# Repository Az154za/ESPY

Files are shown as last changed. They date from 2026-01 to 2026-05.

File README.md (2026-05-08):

# ESPY:
The main mcu is the esp32-P4 that allows fast lane data transmission allowing the camera and display option .
This project contains 4 layers 2 for signals 1 for 3V3 and one for Ground .  

The reason I chose the p4 is because it's very good for cameras .

-- feel free to grab gerber file and to print them yourself --
# Schematic :



# Routing :



# 3D overview : 


# BOM ( visual ) 

Total:192$

I hope you like this project

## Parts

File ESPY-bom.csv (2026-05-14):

Name | Purpose | Quantity | Total Cost (USD) | Link | Distributor
JLCPCB fees | Production fees | 1 | 96.00 |  | JLCPCB
JLCPCB fees | Price tolerance inflation | 1 | 5.00 |  | JLCPCB
Camera | Testing | 1 | 10.44 | https://fr.aliexpress.com/item/1005003386791483.html?pdp_ext_f=%7B"order"%3A"2144"%2C"spu_best_type"%3A"price"%2C"eval"%3A"1"%2C"fromPage"%3A"search"%7D&pdp_npi=6%40dis%21EUR%213.62%210.99%21%21%214.15%211.13%21%40211b813b17782729390364065e89b5%2112000034511448969%21sea%21FR%210%21ABX%211%210%21n_tag%3A-29910%3Bd%3A3d505027%3Bm03_new_user%3A-29895%3BpisId%3A5000000203225082&curPageLogUid=UVp1q8ZxinQD&utparam-url=scene%3Asearch%7Cquery_from%3A%7Cx_object_id%3A1005003386791483%7C_p_origin_prod%3A | ALIEXPRESS
C481407 | Crystal | 5 | 1.25 | https://jlcpcb.com/partdetail/NDK-NX3225GA_12MHZ_STD_CRG2/C481407 | JLCPCB
C5380316 | Crystal | 6 | 0.42 | https://jlcpcb.com/partdetail/SST-3225_40M_12PF10PPM/C5380316 | JLCPCB
C2962011 | FLASH SHIP ( 512 Mbits ) | 2 | 16.15 | https://jlcpcb.com/partdetail/WinbondElec-W25Q512JVFIQ/C2962011 | JLCPCB
C6798314 | USB_HUB ( SL2.1A ) | 2 | 0.53 | https://jlcpcb.com/partdetail/CoreChips-SL21A/C6798314 | JLCPCB
C398367 | Buck converters | 6 | 0.88 | https://jlcpcb.com/partdetail/TexasInstruments-TLV62569ADRLR/C398367 | JLCPCB
C22387510 | ESP-P4 | 2 | 11.58 | https://jlcpcb.com/partdetail/EspressifSystems-ESP32P4NRW32/C22387510 | JLCPCB
C115357 | switch | 5 | 0.66 | https://jlcpcb.com/partdetail/ALPSALPINE-SKRKAEE020/C115357 | JLCPCB
C137946 | resistor | 20 | 0.02 | https://jlcpcb.com/partdetail/YAGEO-RC0402FR076K2L/C137946 | JLCPCB
C25905 | resistor | 20 | 0.02 | https://jlcpcb.com/partdetail/26648-0402WGF5101TCE/C25905 | JLCPCB
C43251 | resistor | 20 | 0.02 | https://jlcpcb.com/partdetail/44242-0402WGF4021TCE/C43251 | JLCPCB
C25744 | resistor | 20 | 0.03 | https://jlcpcb.com/partdetail/26487-0402WGF1002TCE/C25744 | JLCPCB
C17168 | resistor | 42 | 0.03 | https://jlcpcb.com/partdetail/17853-0402WGF0000TCE/C17168 | JLCPCB
C2998054 | resistor | 20 | 0.01 | https://jlcpcb.com/partdetail/FOJAN-FRC0402F4993TS/C2998054 | JLCPCB
C1035 | Inductor | 20 | 0.39 | https://jlcpcb.com/partdetail/Sunlord-SDFL1608S100KTF/C1035 | JLCPCB
C383389 | Inductor | 6 | 0.35 | https://jlcpcb.com/partdetail/TDK-MLZ1005M2R2WT000/C383389 | JLCPCB
C3020560 | USB_C receptacle | 4 | 4.40 | https://jlcpcb.com/partdetail/3542626-USB4105_GFA/C3020560 | JLCPCB
C22360337 | Display and camera connector | 5 | 0.48 | https://jlcpcb.com/partdetail/23804216-FPC0_5B_WTG15P/C22360337 | JLCPCB
C15195 | Capacitor | 20 | 0.03 | https://jlcpcb.com/partdetail/15869-CL05B103KB5NNNC/C15195 | JLCPCB
C15525 | Capacitor | 20 | 0.13 | https://jlcpcb.com/partdetail/16204-CL05A106MQ5NUNC/C15525 | JLCPCB
C52923 | Capacitor | 24 | 0.09 | https://jlcpcb.com/partdetail/53938-CL05A105KA5NQNC/C52923 | JLCPCB
C1525 | Capacitor | 54 | 0.07 | https://jlcpcb.com/partdetail/1877-CL05B104KO5NNNC/C1525 | JLCPCB
C32949 | Capacitor | 20 | 0.09 | https://jlcpcb.com/partdetail/33914-CL05C100JB5NNNC/C32949 | JLCPCB
C415703 | Capacitor | 10 | 0.50 | https://jlcpcb.com/partdetail/408393-GRM155R60J226ME11D/C415703 | JLCPCB
C1555 | Capacitor | 20 | 0.03 | https://jlcpcb.com/partdetail/1907-0402CG220J500NT/C1555 | JLCPCB
C23733 | Capacitor | 20 | 0.12 | https://jlcpcb.com/partdetail/24469-CL05A475MP5NRNC/C23733 | JLCPCB

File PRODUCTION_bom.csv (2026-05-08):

Designator | Footprint | Quantity | Value | LCSC Part #
C1, C9 | 0402 | 2 | 4.7uF
C10, C12, C13, C15, C16, C22, C24, C25, C26, C28, C29, C31, C33, C34, C35, C36, C41, C42, C43, C44, C6, C8 | 0402 | 22 | 0.1uF
C11, C17, C18, C19, C20, C23, C27 | 0402 | 7 | 1uF
C14, C30, C32, C37, C38 | 0402 | 5 | 10uF
C2 | 0402 | 1 | 22pF
C21, C7 | 0402 | 2 | 10nF
C3, C49, C50 | 0402 | 3 | 22uF
C4, C5 | 0402 | 2 | 10pF
J1, J5 | Molex_502244-1530_1x15-1MP_P0.5mm_Horizontal | 2 | Conn_01x15_Socket
J2, J3 | USB_C_Receptacle_GCT_USB4105-xx-A_16P_TopMnt_Horizontal | 2 | USB_C_Receptacle_USB2.0_16P
J6 | PinHeader_2x10_P2.54mm_Vertical | 1 | Conn_01x20_Pin
J7 | PinHeader_1x08_P2.54mm_Vertical | 1 | Conn_01x08_Pin
J9 | PinHeader_2x08_P2.54mm_Vertical | 1 | Conn_01x16_Pin
L1 | 0402 | 1 | 2.2uH
L2 | 0603 | 1 | 10uH
R1, R2 | 0402 | 2 | 499k
R10, R11, R12, R13, R14, R15, R16, R17, R18, R20, R3, R4, R6, R7, R8, R9 | 0402 | 16 | 0
R19, R35, R5 | 0402 | 3 | 10k
R21, R22 | 0402 | 2 | 4.02k
R25, R26, R27, R28 | 0402 | 4 | 5.1k
R36 | 0402 | 1 | 6.2k
SW1 | SW_Push_SPST_NO_Alps_SKRK | 1 | SW_DPST_x2
U1 | ESP32-P4 | 1 | ~
U2, U4 | SOT-563 | 2 | TLV62569ADRL
U6 | SOIC-16_4.55x10.3mm_P1.27mm | 1 | SL2.1A
W25Q512JVFIQ1 | SOIC-16W_7.5x10.3mm_P1.27mm | 1 | ~
Y1 | Oscillator_SMD_Abracon_ASE-4Pin_3.2x2.5mm | 1 | 40Mhz(+/-10ppm)
Y2 | Crystal_SMD_3215-2Pin_3.2x1.5mm | 1 | 12Mhz

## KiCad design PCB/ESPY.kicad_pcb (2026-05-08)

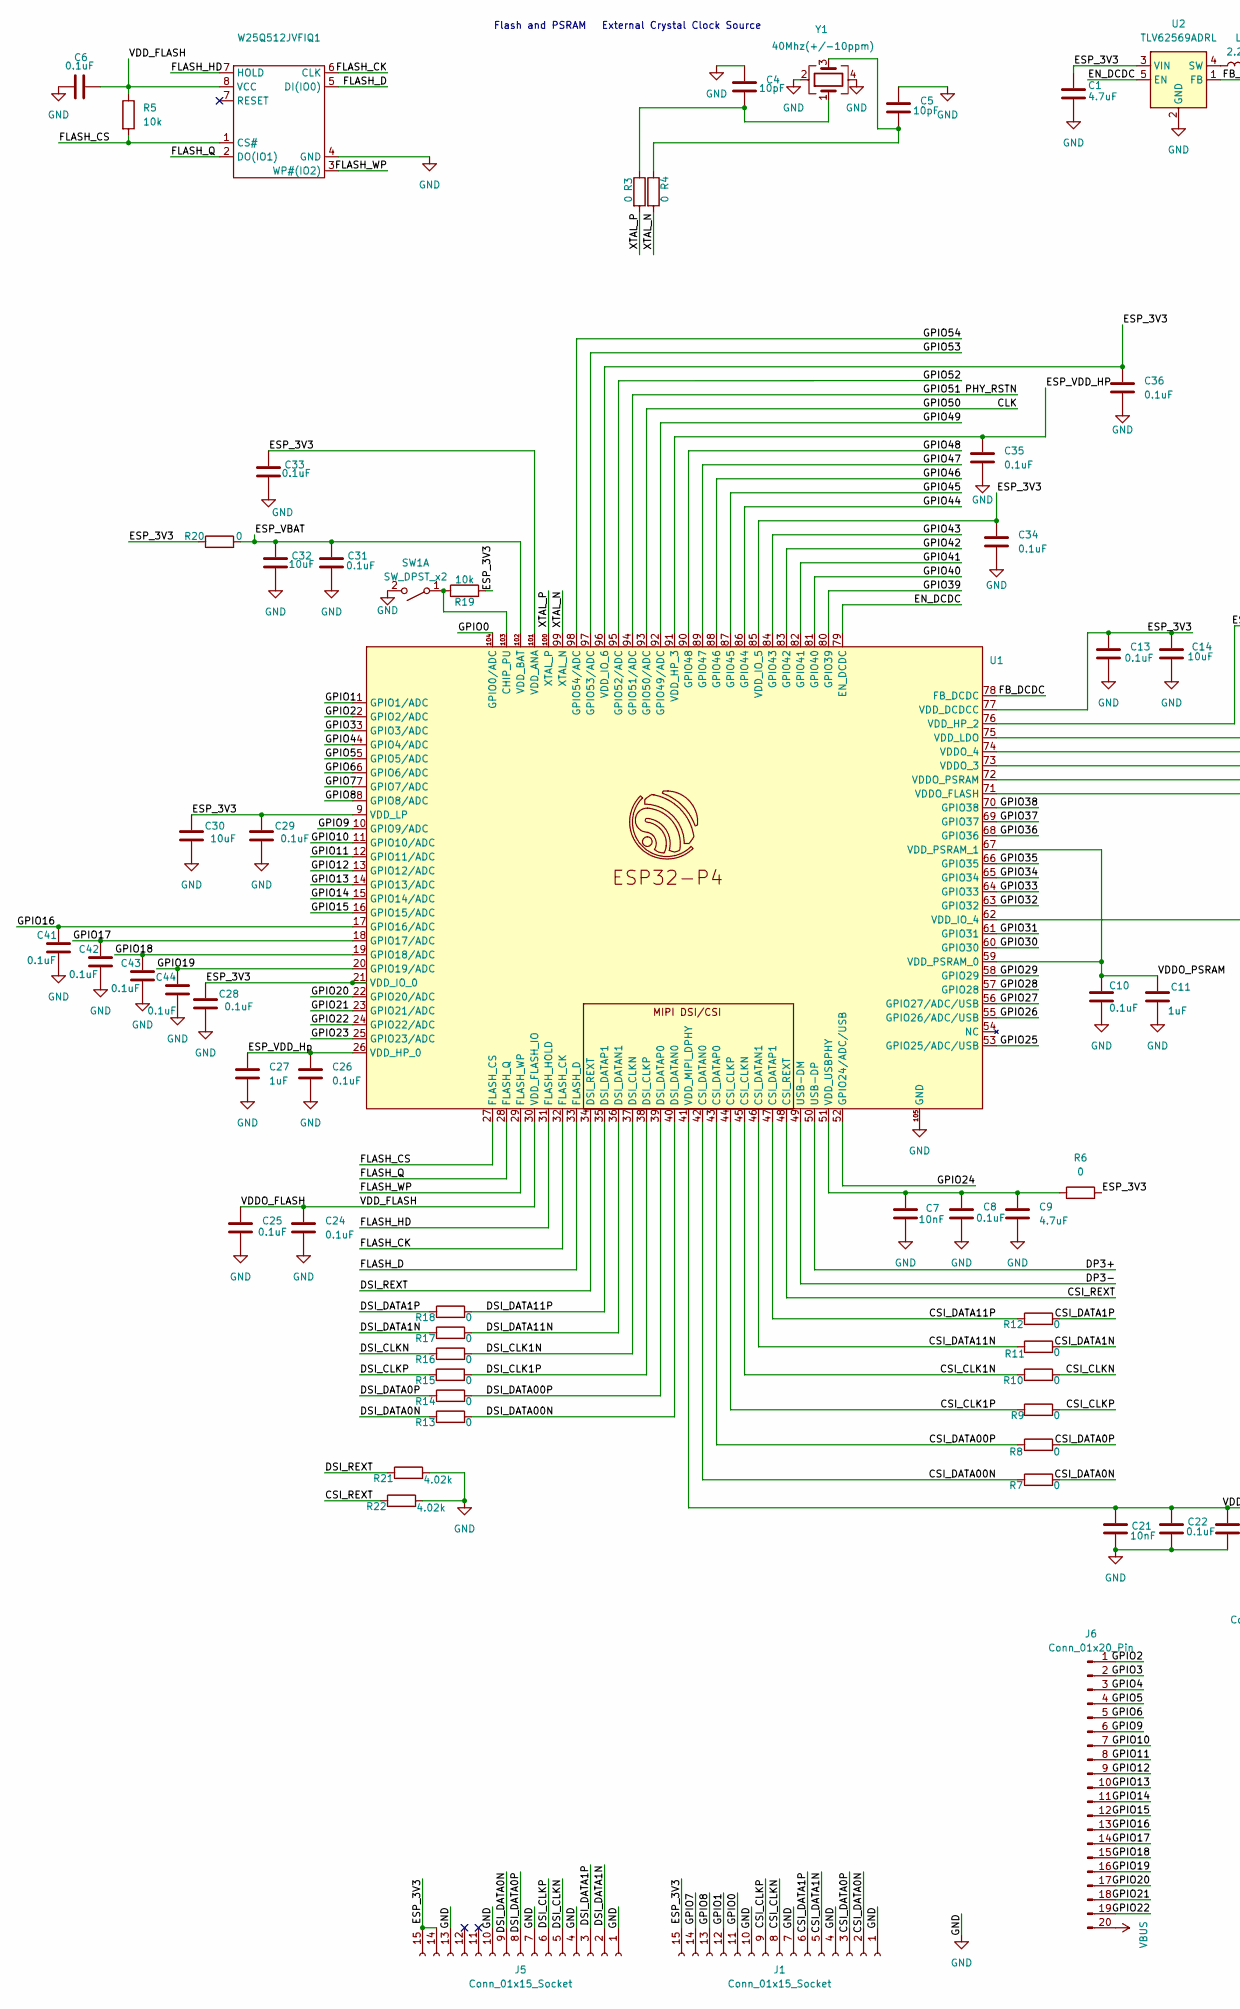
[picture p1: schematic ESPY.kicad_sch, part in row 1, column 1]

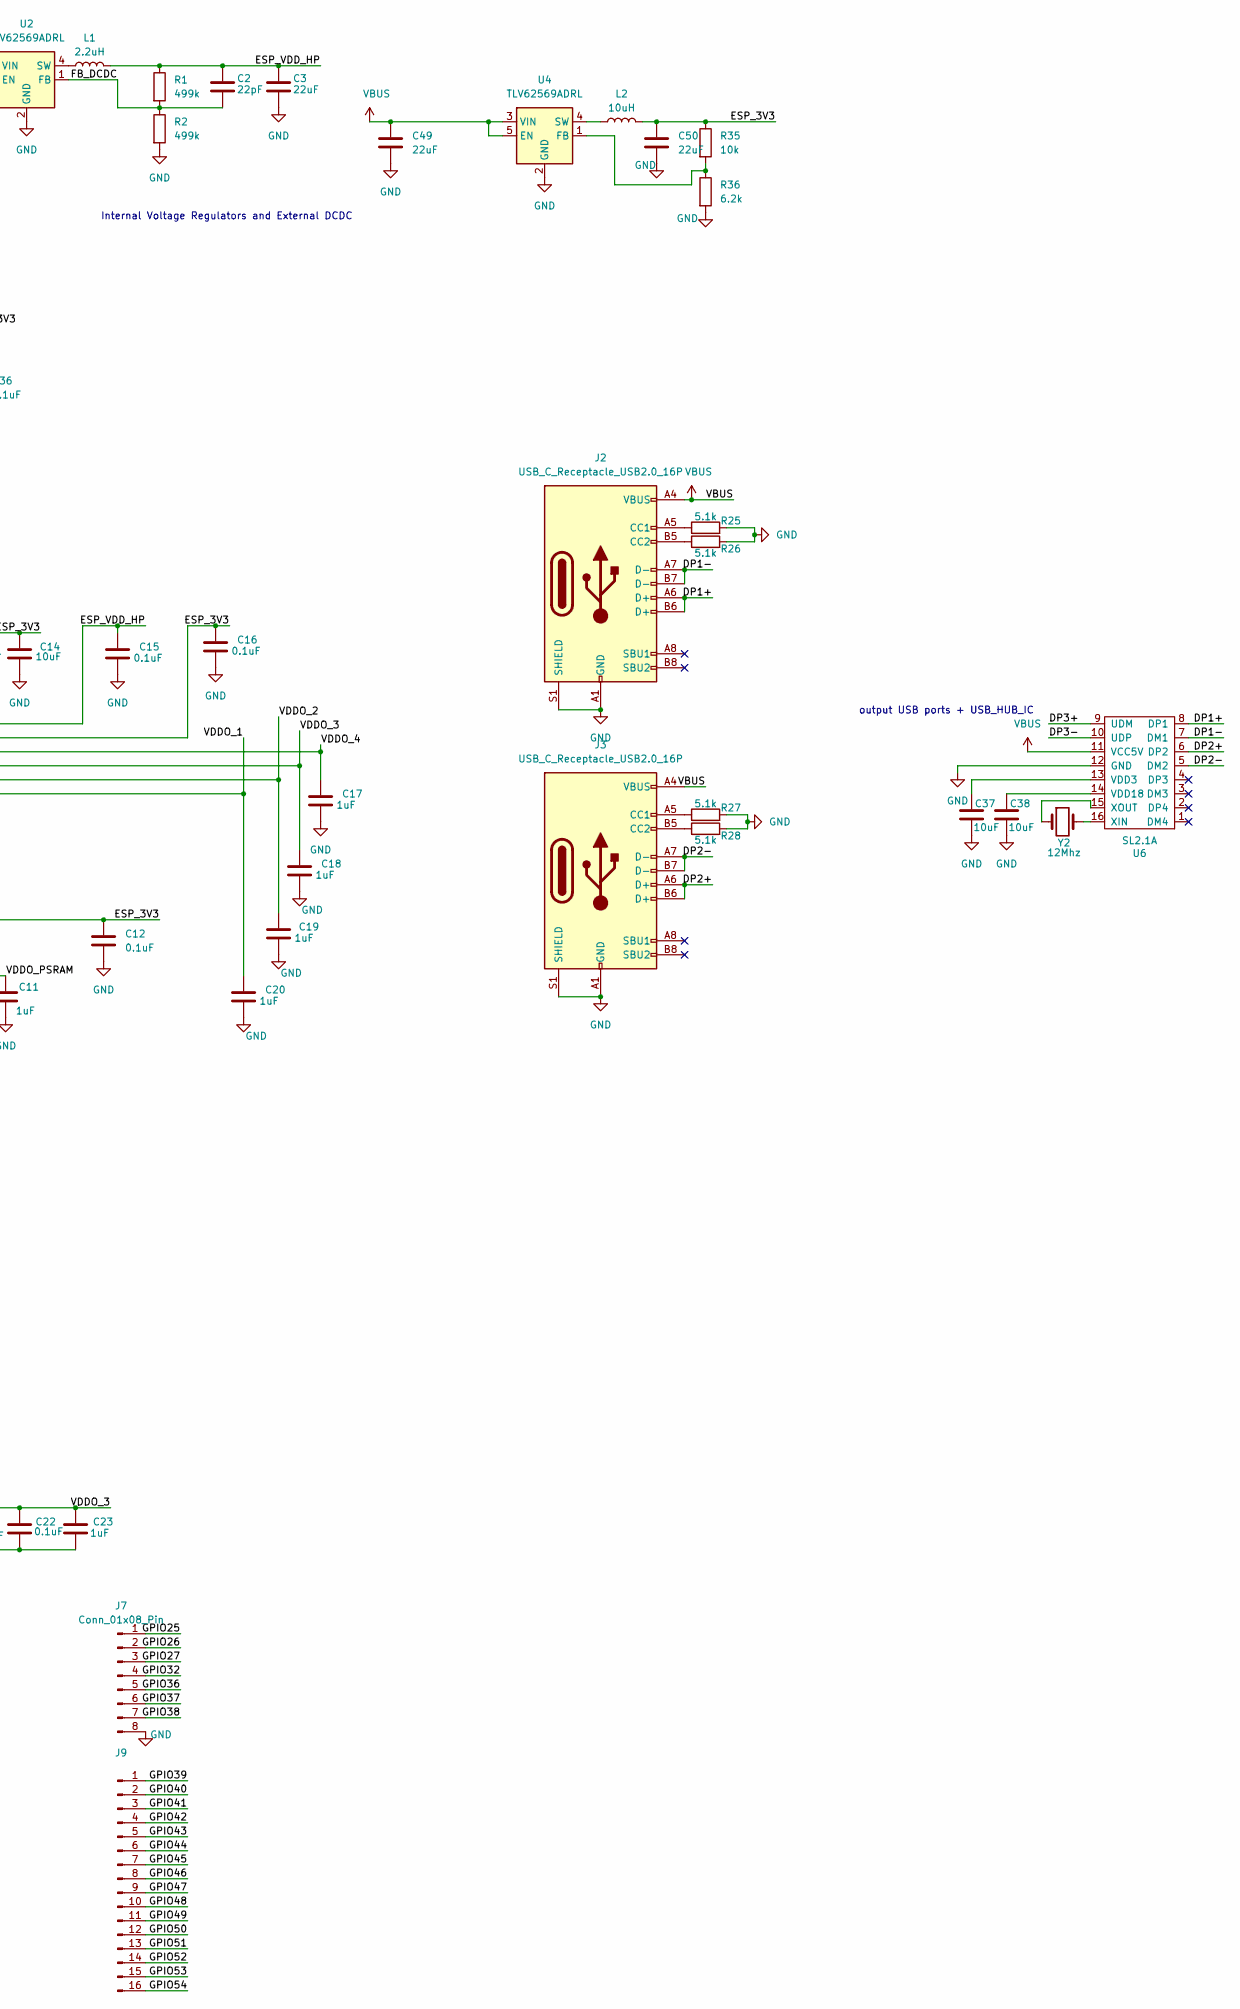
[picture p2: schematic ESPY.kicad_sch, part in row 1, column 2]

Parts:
C1, C9: 4.7uF; C_0402_1005Metric
C2: 22pF; C_0402_1005Metric
C3, C49, C50: 22uF; C_0402_1005Metric
C4, C5: 10pF; C_0402_1005Metric
C6, C8, C10, C12, C13, C15, C16, C22, C24, C25, C26, C28, C29, C31, C33, C34, C35, C36, C41, C42, C43, C44: 0.1uF; C_0402_1005Metric
C7, C21: 10nF; C_0402_1005Metric
C11, C17, C18, C19, C20, C23, C27: 1uF; C_0402_1005Metric
C14, C30, C32, C37, C38: 10uF; C_0402_1005Metric
J1, J5: Conn_01x15_Socket; Molex_502244-1530_1x15-1MP_P0.5mm_Horizontal
J2, J3: USB_C_Receptacle_USB2.0_16P; USB_C_Receptacle_GCT_USB4105-xx-A_16P_TopMnt_Horizontal
J6: Conn_01x20_Pin; PinHeader_2x10_P2.54mm_Vertical
J7: Conn_01x08_Pin; PinHeader_1x08_P2.54mm_Vertical
J9: Conn_01x16_Pin; PinHeader_2x08_P2.54mm_Vertical
L1: 2.2uH; L_0402_1005Metric
L2: 10uH; L_0603_1608Metric
R1, R2: 499k; R_0402_1005Metric
R3, R4, R6, R7, R8, R9, R10, R11, R12, R13, R14, R15, R16, R17, R18, R20: 0; R_0402_1005Metric
R5, R19, R35: 10k; R_0402_1005Metric
R21, R22: 4.02k; R_0402_1005Metric
R25, R26, R27, R28: 5.1k; R_0402_1005Metric
R36: 6.2k; R_0402_1005Metric
SW1: SW_DPST_x2; SW_Push_SPST_NO_Alps_SKRK
U1: ESP32-P4
U2, U4: TLV62569ADRL; SOT-563
U6: SL2.1A; SOIC-16_4.55x10.3mm_P1.27mm
W25Q512JVFIQ1: SOIC-16W_7.5x10.3mm_P1.27mm
Y1: 40Mhz(+/-10ppm); Oscillator_SMD_Abracon_ASE-4Pin_3.2x2.5mm
Y2: 12Mhz; Crystal_SMD_3215-2Pin_3.2x1.5mm

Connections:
/CLK: J9.12, U1.93 (GPIO50/ADC)
/CSI_CLK1N: R10.1, U1.45 (CSI_CLKN)
/CSI_CLK1P: R9.1, U1.44 (CSI_CLKP)
/CSI_CLKN: J1.8, R10.2
/CSI_CLKP: J1.9, R9.2
/CSI_DATA00N: R7.1, U1.42 (CSI_DATAN0)
/CSI_DATA0N: J1.2, R7.2
/CSI_DATA00P: R8.1, U1.43 (CSI_DATAP0)
/CSI_DATA0P: J1.3, R8.2
/CSI_DATA1N: J1.5, R11.2
/CSI_DATA1P: J1.6, R12.2
/CSI_DATA11N: R11.1, U1.46 (CSI_DATAN1)
/CSI_DATA11P: R12.1, U1.47 (CSI_DATAP1)
/CSI_REXT: R22.1, U1.48 (CSI_REXT)
/DP1+: J2.A6 (D+), J2.B6 (D+), U6.8 (DP1)
/DP1-: J2.A7 (D-), J2.B7 (D-), U6.7 (DM1)
/DP2+: J3.A6 (D+), J3.B6 (D+), U6.6 (DP2)
/DP2-: J3.A7 (D-), J3.B7 (D-), U6.5 (DM2)
/DP3+: U1.50 (USB-DP), U6.9 (UDM)
/DP3-: U1.49 (USB-DM), U6.10 (UDP)
/DSI_CLK1N: R16.2, U1.37 (DSI_CLKN)
/DSI_CLK1P: R15.2, U1.38 (DSI_CLKP)
/DSI_CLKN: J5.5, R16.1
/DSI_CLKP: J5.6, R15.1
/DSI_DATA0N: J5.9, R13.1
/DSI_DATA00N: R13.2, U1.40 (DSI_DATAN0)
/DSI_DATA0P: J5.8, R14.1
/DSI_DATA00P: R14.2, U1.39 (DSI_DATAP0)
/DSI_DATA1N: J5.2, R17.1
/DSI_DATA1P: J5.3, R18.1
/DSI_DATA11N: R17.2, U1.36 (DSI_DATAN1)
/DSI_DATA11P: R18.2, U1.35 (DSI_DATAP1)
/DSI_REXT: R21.1, U1.34 (DSI_REXT)
/EN_DCDC: U1.79 (EN_DCDC), U2.5 (EN)
/ESP_3V3: C1.1, C12.1, C13.1, C14.1, C16.1, C28.1, C29.1, C30.1, C33.1, C34.1, C36.1, C50.1, J1.15, J5.14, J5.15, L2.2, R6.2, R19.2, R20.1, R35.1, U1.9 (VDD_LP), U1.21 (VDD_IO_0), U1.62 (VDD_IO_4), U1.75 (VDD_LDO), U1.77 (VDD_DCDCC), U1.85 (VDD_IO_5), U1.96 (VDD_IO_6), U1.101 (VDD_ANA), U2.3 (VIN)
/ESP_VBAT: C31.1, C32.1, R20.2, U1.102 (VDD_BAT)
/ESP_VDD_HP: C2.1, C3.1, C15.1, C35.1, L1.2, R1.1, U1.76 (VDD_HP_2), U1.91 (VDD_HP_3)
/ESP_VDD_Hp: C26.1, C27.1, U1.26 (VDD_HP_0)
/FB_DCDC: C2.2, R1.2, R2.1, U1.78 (FB_DCDC), U2.1 (FB)
/FLASH_CK: U1.32 (FLASH_CK), W25Q512JVFIQ1.6 (CLK)
/FLASH_CS: R5.2, U1.27 (FLASH_CS), W25Q512JVFIQ1.1 (CS#)
/FLASH_D: U1.33 (FLASH_D), W25Q512JVFIQ1.5 (DI(IO0))
/FLASH_HD: U1.31 (FLASH_HOLD), W25Q512JVFIQ1.7 (HOLD)
/FLASH_Q: U1.28 (FLASH_Q), W25Q512JVFIQ1.2 (DO(IO1))
/FLASH_WP: U1.29 (FLASH_WP), W25Q512JVFIQ1.3 (WP#(IO2))
/GPIO0: J1.11, U1.104 (GPIO0/ADC)
/GPIO1: J1.12, U1.1 (GPIO1/ADC)
/GPIO2: J6.1, U1.2 (GPIO2/ADC)
/GPIO3: J6.2, U1.3 (GPIO3/ADC)
/GPIO4: J6.3, U1.4 (GPIO4/ADC)
/GPIO5: J6.4, U1.5 (GPIO5/ADC)
/GPIO6: J6.5, U1.6 (GPIO6/ADC)
/GPIO7: J1.14, U1.7 (GPIO7/ADC)
/GPIO8: J1.13, U1.8 (GPIO8/ADC)
/GPIO9: J6.6, U1.10 (GPIO9/ADC)
/GPIO10: J6.7, U1.11 (GPIO10/ADC)
/GPIO11: J6.8, U1.12 (GPIO11/ADC)
/GPIO12: J6.9, U1.13 (GPIO12/ADC)
/GPIO13: J6.10, U1.14 (GPIO13/ADC)
/GPIO14: J6.11, U1.15 (GPIO14/ADC)
/GPIO15: J6.12, U1.16 (GPIO15/ADC)
/GPIO16: C41.1, J6.13, U1.17 (GPIO16/ADC)
/GPIO17: C42.1, J6.14, U1.18 (GPIO17/ADC)
/GPIO18: C43.1, J6.15, U1.19 (GPIO18/ADC)
/GPIO19: C44.1, J6.16, U1.20 (GPIO19/ADC)
/GPIO20: J6.17, U1.22 (GPIO20/ADC)
/GPIO21: J6.18, U1.23 (GPIO21/ADC)
/GPIO22: J6.19, U1.24 (GPIO22/ADC)
/GPIO23: U1.25 (GPIO23/ADC)
/GPIO24: U1.52 (GPIO24/ADC/USB)
/GPIO25: J7.1, U1.53 (GPIO25/ADC/USB)
/GPIO26: J7.2, U1.55 (GPIO26/ADC/USB)
/GPIO27: J7.3, U1.56 (GPIO27/ADC/USB)
/GPIO28: U1.57 (GPIO28)
/GPIO29: U1.58 (GPIO29)
/GPIO30: U1.60 (GPIO30)
/GPIO31: U1.61 (GPIO31)
/GPIO32: J7.4, U1.63 (GPIO32)
/GPIO33: U1.64 (GPIO33)
/GPIO34: U1.65 (GPIO34)
/GPIO35: U1.66 (GPIO35)
/GPIO36: J7.5, U1.68 (GPIO36)
/GPIO37: J7.6, U1.69 (GPIO37)
/GPIO38: J7.7, U1.70 (GPIO38)
/GPIO39: J9.1, U1.80 (GPIO39)
/GPIO40: J9.2, U1.81 (GPIO40)
/GPIO41: J9.3, U1.82 (GPIO41)
/GPIO42: J9.4, U1.83 (GPIO42)
/GPIO43: J9.5, U1.84 (GPIO43)
/GPIO44: J9.6, U1.86 (GPIO44)
/GPIO45: J9.7, U1.87 (GPIO45)
/GPIO46: J9.8, U1.88 (GPIO46)
/GPIO47: J9.9, U1.89 (GPIO47)
/GPIO48: J9.10, U1.90 (GPIO48)
/GPIO49: J9.11, U1.92 (GPIO49/ADC)
/GPIO51: J9.13, U1.94 (GPIO51/ADC)
/GPIO52: J9.14, U1.95 (GPIO52/ADC)
/GPIO53: J9.15, U1.97 (GPIO53/ADC)
/GPIO54: J9.16, U1.98 (GPIO54/ADC)
/VDDO_1: C20.1, U1.71 (VDDO_FLASH)
/VDDO_2: C19.1, U1.72 (VDDO_PSRAM)
/VDDO_3: C18.1, C21.1, C22.1, C23.1, U1.41 (VDD_MIPI_DPHY), U1.73 (VDDO_3)
/VDDO_4: C17.1, U1.74 (VDDO_4)
/VDDO_FLASH: C6.1, C24.1, C25.1, R5.1, U1.30 (VDD_FLASH_IO), W25Q512JVFIQ1.8 (VCC)
/VDDO_PSRAM: C10.1, C11.1, U1.59 (VDD_PSRAM_0), U1.67 (VDD_PSRAM_1)
/XTAL_N: R4.2, U1.99 (XTAL_N)
/XTAL_P: R3.2, U1.100 (XTAL_P)
GND: C1.2, C3.2, C4.1, C5.1, C6.2, C7.2, C8.2, C9.2, C10.2, C11.2, C12.2, C13.2, C14.2, C15.2, C16.2, C17.2, C18.2, C19.2, C20.2, C21.2, C22.2, C23.2, C24.2, C25.2, C26.2, C27.2, C28.2, C29.2, C30.2, C31.2, C32.2, C33.2, C34.2, C35.2, C36.2, C37.2, C38.2, C41.2, C42.2, C43.2, C44.2, C49.2, C50.2, J1.1, J1.4, J1.7, J1.10, J2.A1 (GND), J2.A12 (GND), J2.B1 (GND), J2.B12 (GND), J2.S1 (SHIELD), J3.A1 (GND), J3.A12 (GND), J3.B1 (GND), J3.B12 (GND), J3.S1 (SHIELD), J5.1, J5.4, J5.7, J5.10, J5.13, J7.8, R2.2, R21.2, R22.2, R25.2, R26.2, R27.2, R28.2, R36.2, SW1.2 (B), U1.105 (GND), U2.2 (GND), U4.2 (GND), U6.12 (GND), W25Q512JVFIQ1.4 (GND), Y1.2, Y1.4
unnamed: C4.2, R3.1, Y1.1
unnamed: C5.2, R4.1, Y1.3
unnamed: J2.A5 (CC1), R25.1
unnamed: J2.B5 (CC2), R26.1
unnamed: J3.A5 (CC1), R27.1
unnamed: J3.B5 (CC2), R28.1
unnamed: R19.1, SW1.1 (A), U1.103 (CHIP_PU)
unnamed: C7.1, C8.1, C9.1, R6.1, U1.51 (VDD_USBPHY)
unnamed: L1.1, U2.4 (SW)
unnamed: R35.2, R36.1, U4.1 (FB)
unnamed: L2.1, U4.4 (SW)
unnamed: C37.1, U6.13 (VDD3)
unnamed: C38.1, U6.14 (VDD18)
unnamed: U6.16 (XIN), Y2.2
unnamed: U6.15 (XOUT), Y2.1
VBUS: C49.1, J2.A4 (VBUS), J2.A9 (VBUS), J2.B4 (VBUS), J2.B9 (VBUS), J3.A4 (VBUS), J3.A9 (VBUS), J3.B4 (VBUS), J3.B9 (VBUS), J6.20, U4.3 (VIN), U4.5 (EN), U6.11 (VCC5V)

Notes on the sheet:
Flash and PSRAM
External Crystal Clock Source
output USB ports + USB_HUB_IC
Internal Voltage Regulators and External DCDC

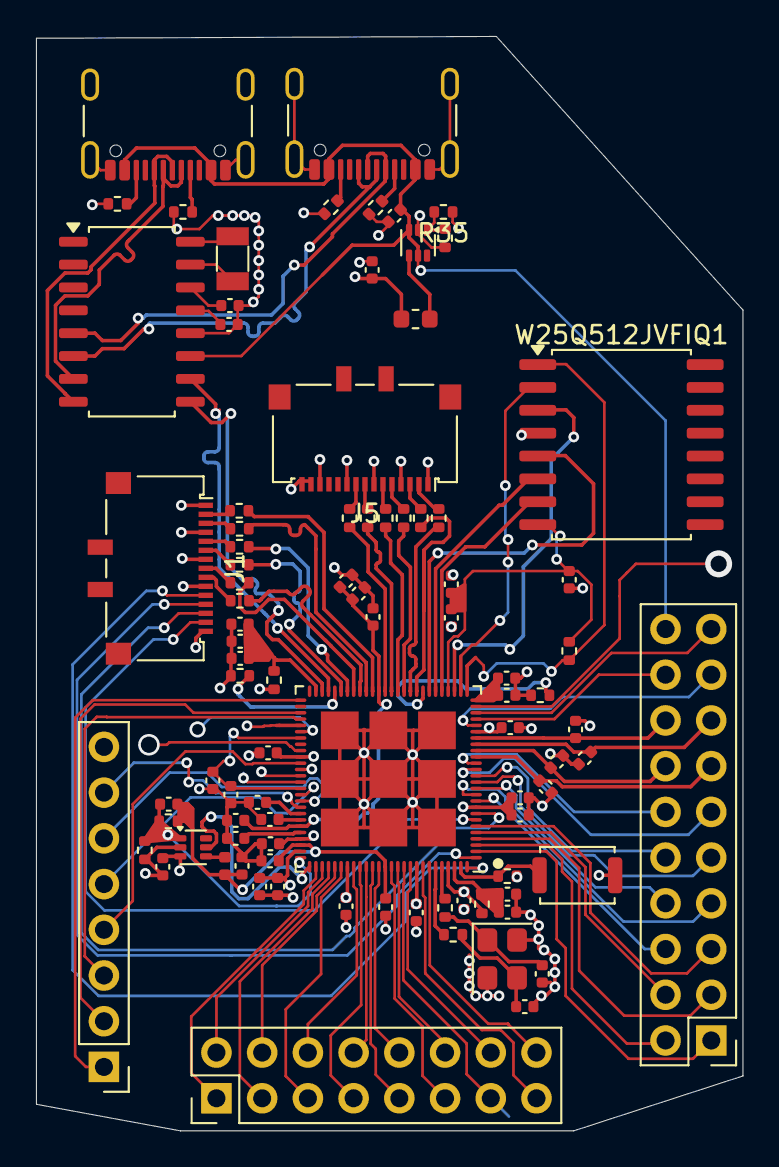
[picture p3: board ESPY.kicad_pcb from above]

Board: 4 copper layers, 39.2 x 60.8 mm, 89 parts (0 on the bottom side), 115 nets.

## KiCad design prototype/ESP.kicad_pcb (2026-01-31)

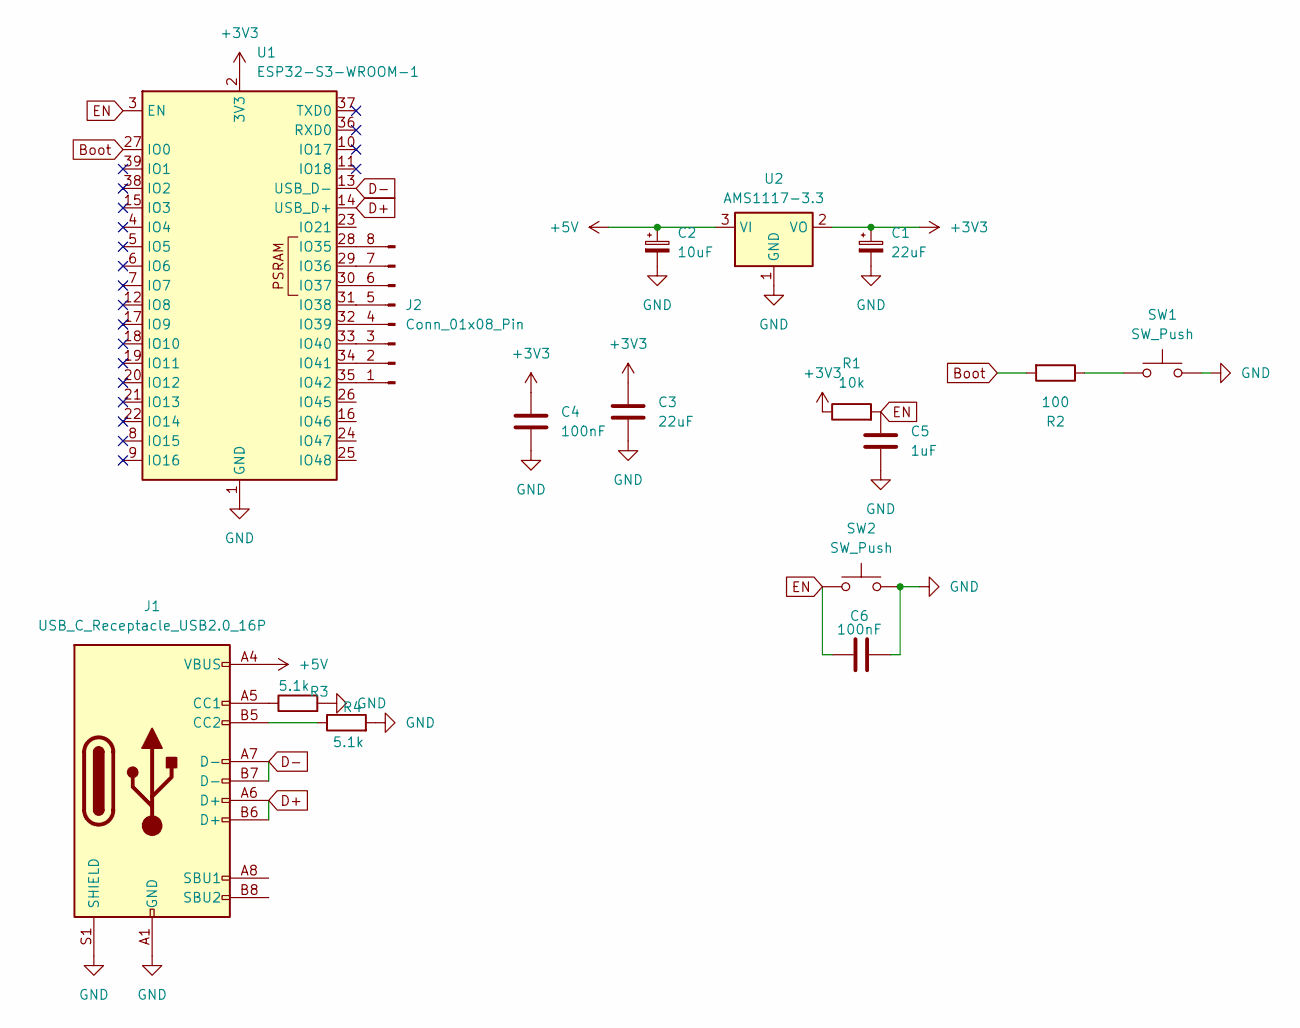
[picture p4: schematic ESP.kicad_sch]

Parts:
C1, C3: 22uF; C_0805_2012Metric_Pad1.18x1.45mm_HandSolder
C2: 10uF; C_0805_2012Metric_Pad1.18x1.45mm_HandSolder
C4, C6: 100nF; C_0805_2012Metric_Pad1.18x1.45mm_HandSolder
C5: 1uF; C_0805_2012Metric_Pad1.18x1.45mm_HandSolder
J1: USB_C_Receptacle_USB2.0_16P; USB_C_Receptacle_HRO_TYPE-C-31-M-12
J2: Conn_01x08_Pin; PinHeader_1x08_P1.00mm_Vertical
R1: 10k; R_0805_2012Metric_Pad1.20x1.40mm_HandSolder
R2: 100; R_0805_2012Metric_Pad1.20x1.40mm_HandSolder
R3, R4: 5.1k; R_0805_2012Metric_Pad1.20x1.40mm_HandSolder
SW1, SW2: SW_Push; SW_SPST_B3U-1000P-B
U1: ESP32-S3-WROOM-1
U2: AMS1117-3.3; SOT-223-3_TabPin2

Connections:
+3V3: C1.1, C3.1, C4.1, R1.1, U1.2 (3V3), U2.2 (VO)
+5V: C2.1, J1.A4 (VBUS), J1.A9 (VBUS), J1.B4 (VBUS), J1.B9 (VBUS), U2.3 (VI)
Boot: R2.2, U1.27 (IO0)
D+: J1.A6 (D+), J1.B6 (D+), U1.14 (USB_D+)
D-: J1.A7 (D-), J1.B7 (D-), U1.13 (USB_D-)
EN: C5.1, C6.1, R1.2, SW2.1, U1.3 (EN)
GND: C1.2, C2.2, C3.2, C4.2, C5.2, C6.2, J1.A1 (GND), J1.A12 (GND), J1.B1 (GND), J1.B12 (GND), J1.S1 (SHIELD), R3.2, R4.2, SW1.2, SW2.2, U1.1 (GND), U1.40 (GND), U1.41 (GND), U2.1 (GND)
unnamed: J1.A5 (CC1), R3.1
unnamed: J1.B5 (CC2), R4.1
unnamed: J2.1, U1.35 (IO42)
unnamed: J2.2, U1.34 (IO41)
unnamed: J2.3, U1.33 (IO40)
unnamed: J2.4, U1.32 (IO39)
unnamed: J2.5, U1.31 (IO38)
unnamed: J2.6, U1.30 (IO37)
unnamed: J2.7, U1.29 (IO36)
unnamed: J2.8, U1.28 (IO35)
unnamed: R2.1, SW1.1

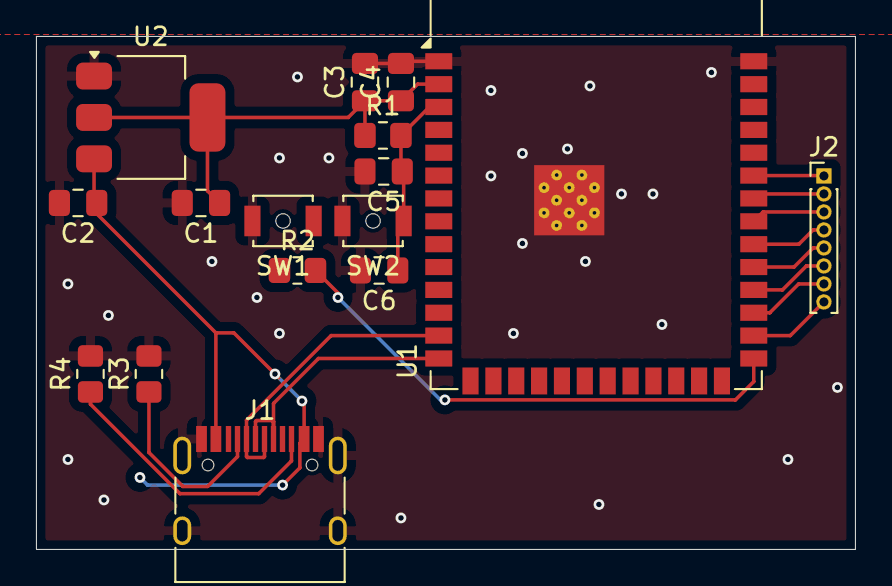
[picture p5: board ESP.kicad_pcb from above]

Board: 2 copper layers, 45.5 x 28.5 mm, 16 parts (0 on the bottom side), 18 nets.

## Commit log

2026-04-21 Update README with project details and schematic
    Added project description and schematic image to README.
2026-05-07 Saved my files
    [ESPY.kicad_pcb, ESPY.kicad_sch, PRODUCTION_bom.csv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]
2026-05-08 files saved
    [ESPY.kicad_pcb, ESPY.kicad_sch, PRODUCTION_bom.csv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]
